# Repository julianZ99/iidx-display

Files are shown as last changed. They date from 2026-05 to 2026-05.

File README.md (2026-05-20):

# IIDX Display

> **WIP** — PCB design complete, firmware and PC bridge not yet implemented.
> Untested — hardware not yet fabricated/assembled.

DIY 9-digit 16-segment display for beatmania IIDX and general PC use.

Reads the ticker from [spice2x](https://github.com/spice2x/spice2x.github.io) via its
TCP/JSON API (`ticker_get`) and displays it on 9x 16-segment digits.

## Hardware

- **MCU:** Waveshare RP2040 Zero
- **Drivers:** 2x HOLTEK HT16K33 (I2C LED matrix driver)
- **Displays:** 9x Kingbright PSC08-11SURKWA (0.8", red, common cathode, 16-segment)
- **Decimals:** 9x individual GPIO-driven decimal points

### Pinout

| Func | RP2040 GPIO |
|---|---|
| I2C SDA | GPIO0 |
| I2C SCL | GPIO1 |
| DP1-DP9 | GPIO2-GPIO10 |

### I2C Layout

Both HT16K33 share the same I2C bus. U1 drives displays 1-5 (COM0-COM4) and all 16
segment lines. U2 drives displays 6-9 (COM1-COM4) with ROW0-2 paralleled to U1 for
segments A/B/C (extra current drive).

U2 address is set via a diode+resistor network on the AD/COM0 pin.

### PCB

KiCad design files are in `pcb/`. Footprint library: `pcb/iidx-library.pretty/`.

## Architecture

```
┌──────────┐    TCP/JSON     ┌──────────────┐   USB Serial   ┌──────────────────┐
│  spice2x  │ ─────────────→ │ pc-bridge/   │ ─────────────→ │ RP2040 Zero      │
│  (-api)   │  ticker_get()  │ bridge.py    │  9 raw bytes   │   2× HT16K33     │
└──────────┘                 └──────────────┘                │   9× 16seg DPs   │
                                                              └──────────────────┘
```

The game ticker is 9 characters (`IIDXIO_LED_TICKER[10]` in spice2x's
`games/iidx/iidx.h`). The PC bridge polls `ticker_get()` via the TCP API and forwards
the string over USB serial to the Pico.

### Project Structure

```
├── pcb/                  KiCad design files
├── firmware/             Pico SDK C/C++ source
│   └── src/
│       ├── main.c        init, I2C, USB serial loop
│       ├── ht16k33.c     HT16K33 driver
│       ├── display.c     display buffer, font mapping
│       └── font_16seg.h  ASCII → 16-segment lookup
└── pc-bridge/
    └── bridge.py         spice2x API client → serial
```

## Firmware

C/C++ using the Raspberry Pi Pico SDK. Source in `firmware/`.

### Building

```bash
cd firmware
mkdir build && cd build
cmake ..
make
```

## PC Bridge

Python script that connects to spice2x's TCP API, polls `ticker_get()`, and forwards
the 9-character string over USB serial.

### spice2x Setup

Enable the API: `-api 1337 -apipass yourpass`

API request format (null-terminated JSON):

```json
{"id":1,"module":"iidx","function":"ticker_get","params":[]}
```

Response includes the 9-char ticker string in the `data` field.

## TODO

- [ ] Assemble and test first prototype
- [ ] Implement Pico firmware (I2C init, HT16K33 config, font table, USB serial)
- [ ] Implement PC bridge script (spice2x TCP API → serial)
- [ ] Test with spice2x `-api` ticker data

## License

MIT

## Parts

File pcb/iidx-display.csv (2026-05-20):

Id | Designator | Footprint | Quantity | Designation | Supplier and ref
1 | C1 | C_Elec_6.3x5.4 | 1 | 47µF
2 | C2, C4 | C_0603_1608Metric | 2 | 100nF
3 | C3, C5 | C_0805_2012Metric | 2 | 10µF
4 | D1 | D_SOD-323 | 1 | 1N4148WS
5 | R1, R2 | R_0805_2012Metric_Pad1.20x1.40mm_HandSolder | 2 | 4.7kΩ
6 | R3 | R_0805_2012Metric_Pad1.20x1.40mm_HandSolder | 1 | 39kΩ
7 | R4, R5, R6, R7, R8, R9, R10, R11, R12 | R_0805_2012Metric_Pad1.20x1.40mm_HandSolder | 9 | 330Ω
8 | U1, U2 | SSOP-28_L9.9-W3.9-P0.64-LS6.0-BL | 2 | ~

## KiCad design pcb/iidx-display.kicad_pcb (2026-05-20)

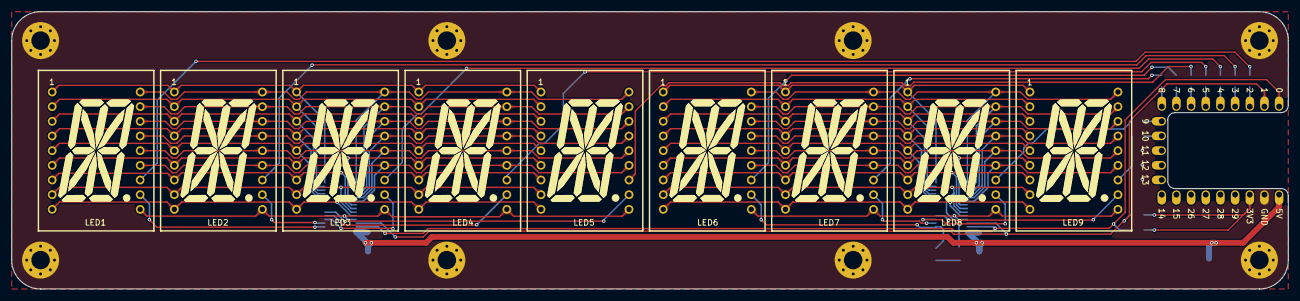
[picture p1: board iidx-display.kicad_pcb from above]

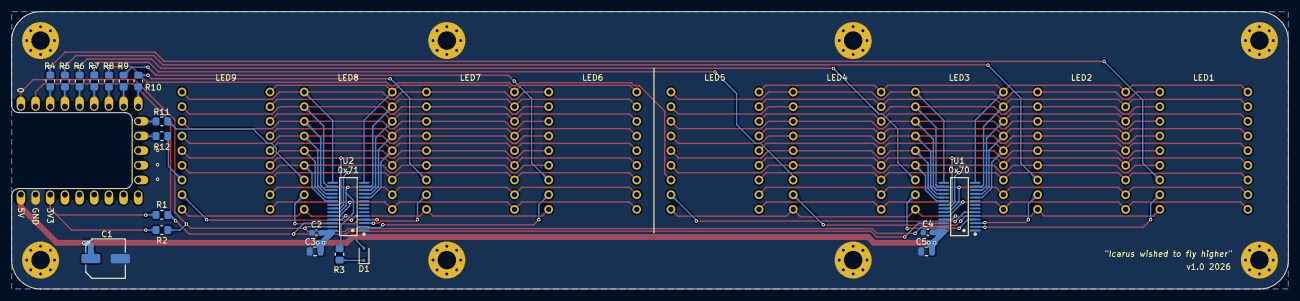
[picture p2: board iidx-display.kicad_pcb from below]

Board: 2 copper layers, 221.0 x 48.0 mm, 38 parts (20 on the bottom side), 65 nets.

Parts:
A1: rp2040 zero; RP2040_Zero_Castellated
C1: 47µF; C_Elec_6.3x5.4
C2, C4: 100nF; C_0603_1608Metric
C3, C5: 10µF; C_0805_2012Metric
D1: 1N4148WS; D_SOD-323
H1, H2, H3, H4, H5, H6, H7, H8: MountingHole_Pad; MountingHole_3.2mm_M3_Pad_Via
LED1, LED2, LED3, LED4, LED5, LED6, LED7, LED8, LED9: LED-SEG-TH_18P-L27.7-W19.9-P2.54-LS15.2_HDSP-3903
R1, R2: 4.7kΩ; R_0805_2012Metric_Pad1.20x1.40mm_HandSolder
R3: 39kΩ; R_0805_2012Metric_Pad1.20x1.40mm_HandSolder
R4, R5, R6, R7, R8, R9, R10, R11, R12: 330Ω; R_0805_2012Metric_Pad1.20x1.40mm_HandSolder
U1, U2: SSOP-28_L9.9-W3.9-P0.64-LS6.0-BL

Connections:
3v3: A1.21 (3V3), R1.2, R2.2
5v: A1.23 (5V), C1.1, C2.2, C3.2, C4.2, C5.2, U1.28 (VDD), U2.28 (VDD)
A0: LED6.8 (g), LED7.8 (g), LED8.8 (g), LED9.8 (g), R3.2, U2.23 (ROW2/A0)
AD: D1.2 (A), LED6.11 (C), U2.2 (COM0/AD)
D1 COM: LED1.11 (C), U1.2 (COM0/AD)
D2 COM: LED2.11 (C), U1.3 (COM1/KS0)
D3 COM: LED3.11 (C), U1.4 (COM2/KS1)
D4 COM: LED4.11 (C), U1.5 (COM3/KS2)
D5 COM: LED5.11 (C), U1.6 (COM4)
D7 COM: LED7.11 (C), U2.3 (COM1/KS0)
D8 COM: LED8.11 (C), U2.4 (COM2/KS1)
D9 COM: LED9.11 (C), U2.5 (COM3/KS2)
DP1: LED1.12 (DP), R4.2
DP2: LED2.12 (DP), R5.2
DP3: LED3.12 (DP), R6.2
DP4: LED4.12 (DP), R7.2
DP5: LED5.12 (DP), R8.2
DP6: LED6.12 (DP), R9.2
DP7: LED7.12 (DP), R10.2
DP8: LED8.12 (DP), R11.2
DP9: LED9.12 (DP), R12.2
GND: A1.22 (GND), C1.2, C2.1, C3.1, C4.1, C5.1, H1.1 (1_1), H2.1 (1_1), H3.1 (1_1), H4.1 (1_1), H5.1 (1_1), H6.1 (1_1), H7.1 (1_1), H8.1 (1_1), U1.1 (VSS), U2.1 (VSS)
GP2: A1.3 (2), R4.1
GP3: A1.4 (3), R5.1
GP4: A1.5 (4), R6.1
GP5: A1.6 (5), R7.1
GP6: A1.7 (6), R8.1
GP7: A1.8 (7), R9.1
GP8: A1.9 (8), R10.1
GP9: A1.10 (9), R11.1
GP10: A1.11 (10), R12.1
unnamed: D1.1 (K), R3.1
SCL: A1.2 (1), R1.1, U1.26 (SCL), U2.26 (SCL)
SDA: A1.1 (0), R2.1, U1.27 (SDA), U2.27 (SDA)
SEG A1: LED1.1 (a), LED2.1 (a), LED3.1 (a), LED4.1 (a), LED5.1 (a), U1.14 (ROW11/K9)
SEG A2: LED6.1 (a), LED7.1 (a), LED8.1 (a), LED9.1 (a), U2.14 (ROW11/K9)
SEG B1: LED1.18 (b), LED2.18 (b), LED3.18 (b), LED4.18 (b), LED5.18 (b), U1.15 (ROW10/K8)
SEG B2: LED6.18 (b), LED7.18 (b), LED8.18 (b), LED9.18 (b), U2.15 (ROW10/K8)
SEG C1: LED1.16 (c), LED2.16 (c), LED3.16 (c), LED4.16 (c), LED5.16 (c), U1.17 (ROW8/K6)
SEG C2: LED6.16 (c), LED7.16 (c), LED8.16 (c), LED9.16 (c), U2.17 (ROW8/K6)
SEG D1: LED1.13 (d), LED2.13 (d), LED3.13 (d), LED4.13 (d), LED5.13 (d), U1.20 (ROW5/K3)
SEG D2: LED6.13 (d), LED7.13 (d), LED8.13 (d), LED9.13 (d), U2.20 (ROW5/K3)
SEG E1: LED1.10 (e), LED2.10 (e), LED3.10 (e), LED4.10 (e), LED5.10 (e), U1.25 (ROW0/A2)
SEG E2: LED6.10 (e), LED7.10 (e), LED8.10 (e), LED9.10 (e), U2.25 (ROW0/A2)
SEG F1: LED1.9 (f), LED2.9 (f), LED3.9 (f), LED4.9 (f), LED5.9 (f), U1.24 (ROW1/A1)
SEG F2: LED6.9 (f), LED7.9 (f), LED8.9 (f), LED9.9 (f), U2.24 (ROW1/A1)
SEG G1: LED1.8 (g), LED2.8 (g), LED3.8 (g), LED4.8 (g), LED5.8 (g), U1.23 (ROW2/A0)
SEG H1: LED1.4 (h), LED2.4 (h), LED3.4 (h), LED4.4 (h), LED5.4 (h), U1.11 (ROW14/K12)
SEG H2: LED6.4 (h), LED7.4 (h), LED8.4 (h), LED9.4 (h), U2.11 (ROW14/K12)
SEG K1: LED1.3 (k), LED2.3 (k), LED3.3 (k), LED4.3 (k), LED5.3 (k), U1.12 (ROW13/K11)
SEG K2: LED6.3 (k), LED7.3 (k), LED8.3 (k), LED9.3 (k), U2.12 (ROW13/K11)
SEG M1: LED1.2 (m), LED2.2 (m), LED3.2 (m), LED4.2 (m), LED5.2 (m), U1.13 (ROW12/K10)
SEG M2: LED6.2 (m), LED7.2 (m), LED8.2 (m), LED9.2 (m), U2.13 (ROW12/K10)
SEG N1: LED1.17 (n), LED2.17 (n), LED3.17 (n), LED4.17 (n), LED5.17 (n), U1.16 (ROW9/K7)
SEG N2: LED6.17 (n), LED7.17 (n), LED8.17 (n), LED9.17 (n), U2.16 (ROW9/K7)
SEG P1: LED1.15 (p), LED2.15 (p), LED3.15 (p), LED4.15 (p), LED5.15 (p), U1.18 (ROW7/K5)
SEG P2: LED6.15 (p), LED7.15 (p), LED8.15 (p), LED9.15 (p), U2.18 (ROW7/K5)
SEG R1: LED1.14 (r), LED2.14 (r), LED3.14 (r), LED4.14 (r), LED5.14 (r), U1.19 (ROW6/K4)
SEG R2: LED6.14 (r), LED7.14 (r), LED8.14 (r), LED9.14 (r), U2.19 (ROW6/K4)
SEG S1: LED1.6 (s), LED2.6 (s), LED3.6 (s), LED4.6 (s), LED5.6 (s), U1.21 (ROW4/K2)
SEG S2: LED6.6 (s), LED7.6 (s), LED8.6 (s), LED9.6 (s), U2.21 (ROW4/K2)
SEG T1: LED1.7 (t), LED2.7 (t), LED3.7 (t), LED4.7 (t), LED5.7 (t), U1.22 (ROW3/K1)
SEG T2: LED6.7 (t), LED7.7 (t), LED8.7 (t), LED9.7 (t), U2.22 (ROW3/K1)
SEG U1: LED1.5 (u), LED2.5 (u), LED3.5 (u), LED4.5 (u), LED5.5 (u), U1.10 (ROW15/K13/INT)
SEG U2: LED6.5 (u), LED7.5 (u), LED8.5 (u), LED9.5 (u), U2.10 (ROW15/K13/INT)
